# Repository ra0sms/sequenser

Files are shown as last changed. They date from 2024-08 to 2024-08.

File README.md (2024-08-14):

# Sequencer

More information - https://ra0sms.com/sequencer-2/

It works in two modes:

1. PA BIAS mode (`MODE` jumper is opened)

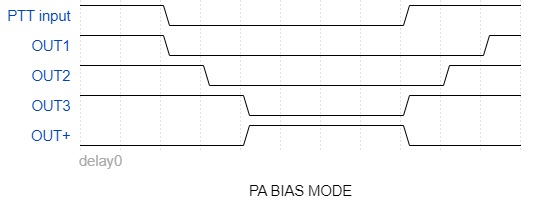
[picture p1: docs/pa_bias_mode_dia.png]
pa_bias_mode_dia
   

2. LNA mode (`MODE` jumper is closed)

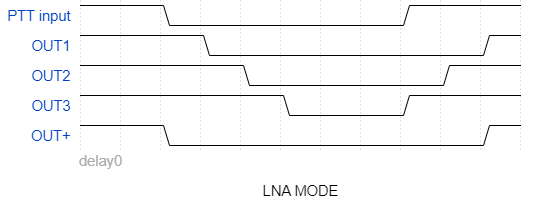
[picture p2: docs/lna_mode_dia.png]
lna_mode_dia
   

--------------------------------------------------------------
PCB dimension: 70*45mm

Consumption current: 30mA

Switch current: up to 1A

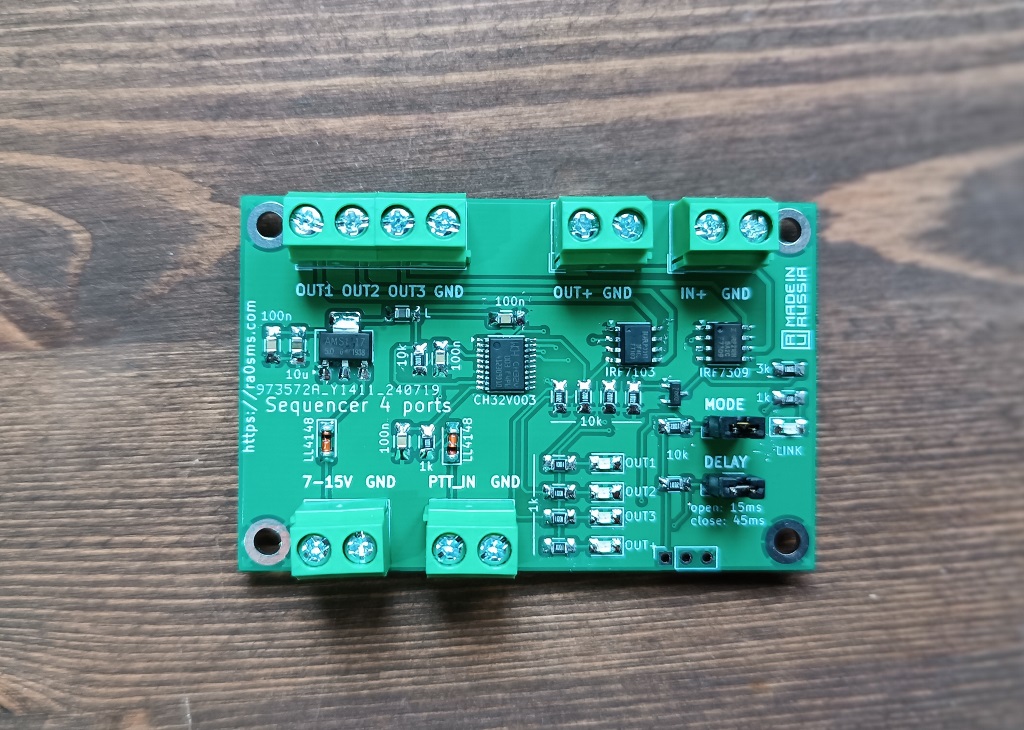
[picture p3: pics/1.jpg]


### Schematic

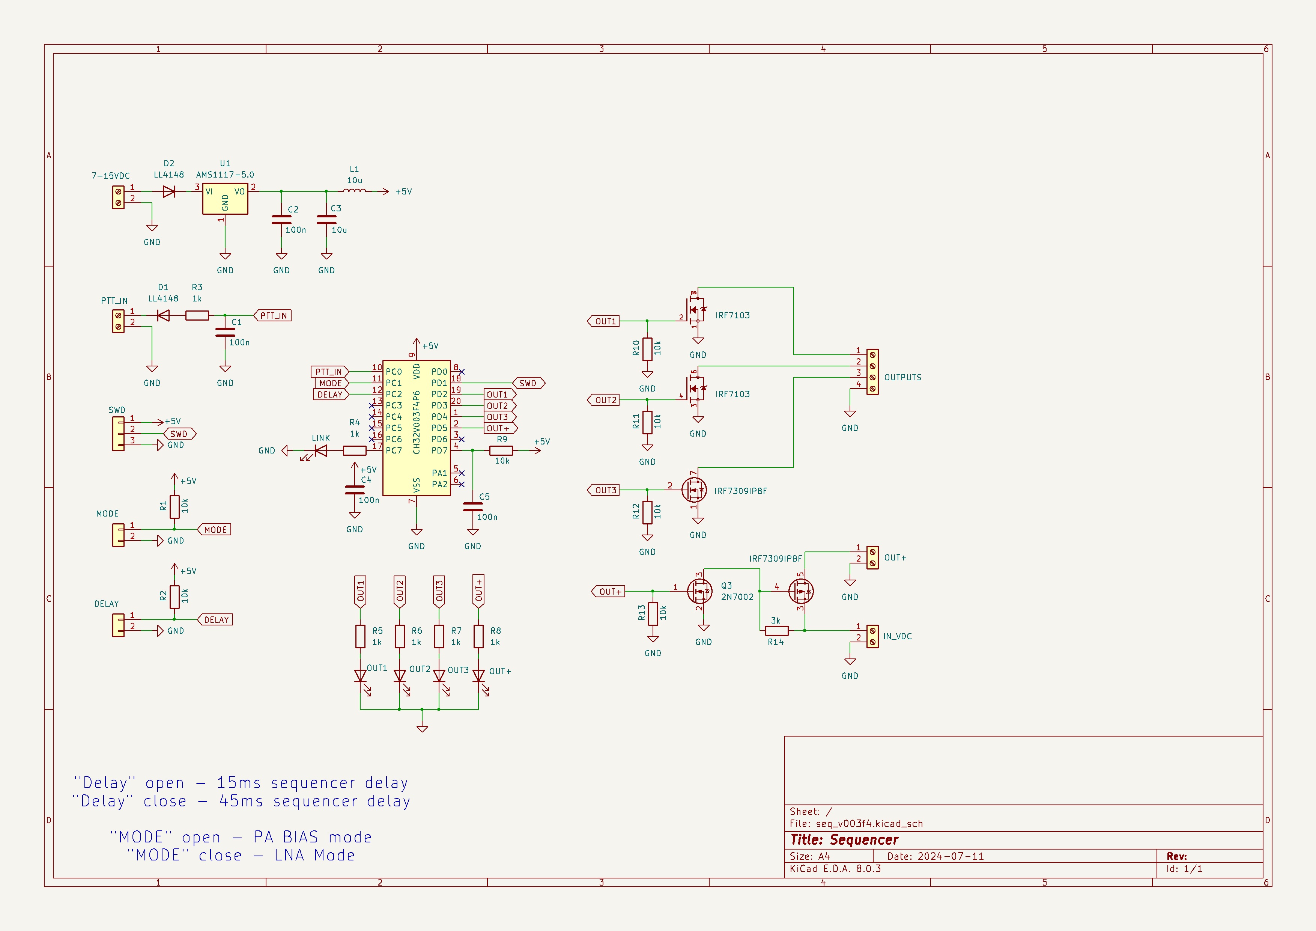
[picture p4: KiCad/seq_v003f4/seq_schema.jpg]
seq_schema


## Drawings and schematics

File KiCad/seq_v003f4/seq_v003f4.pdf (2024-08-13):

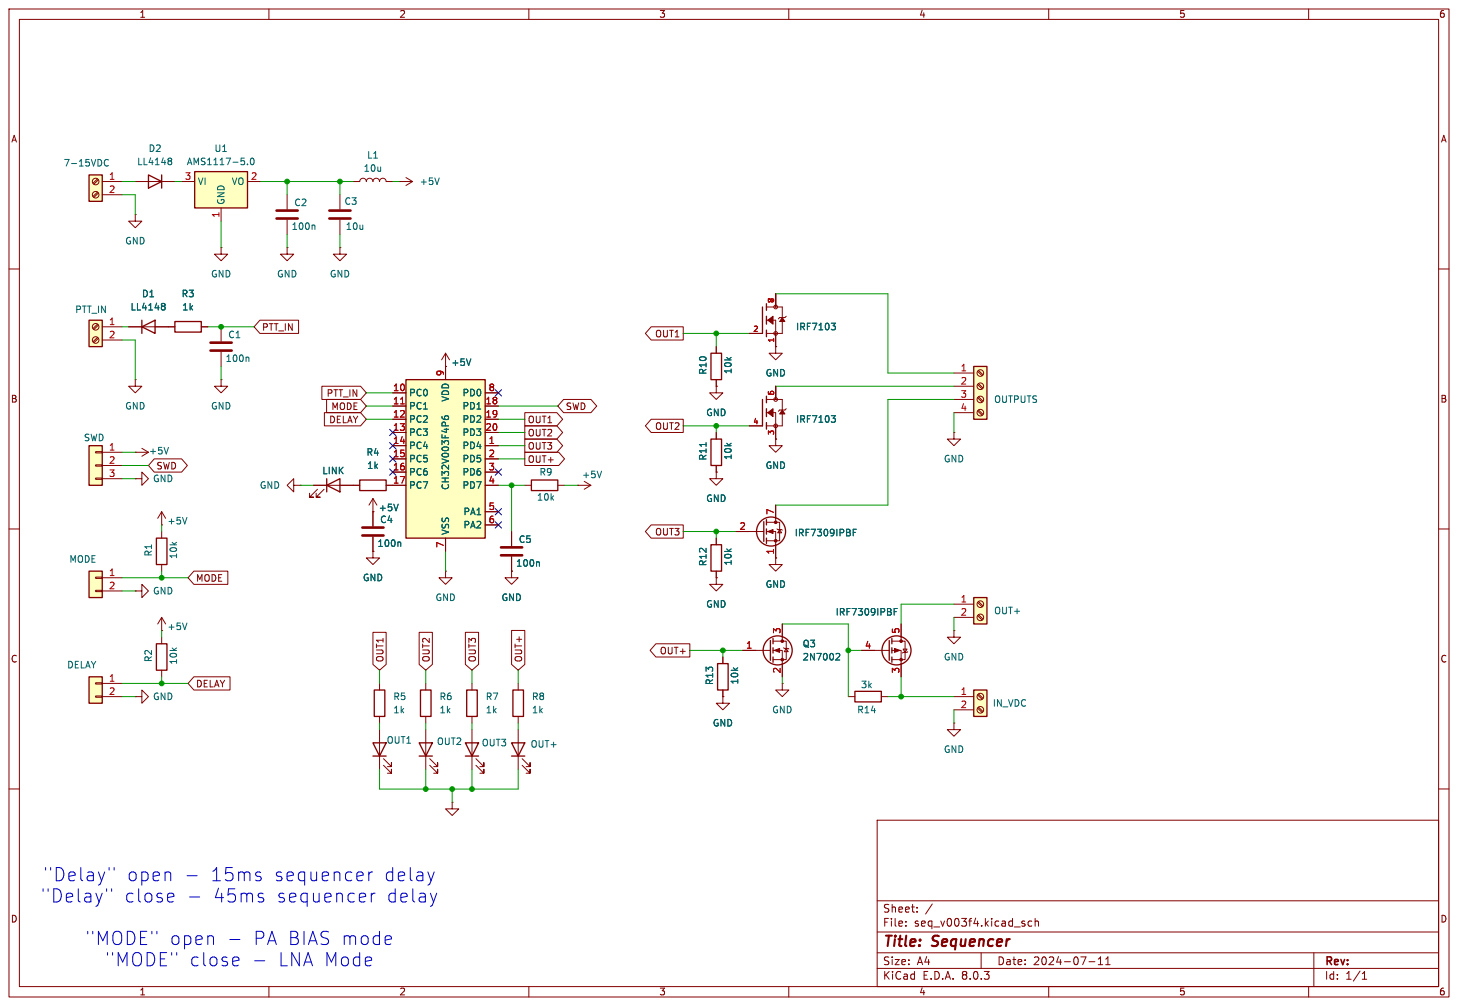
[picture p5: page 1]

Id: 1/1 Title: Sequencer File: seq_v003f4.kicad_sch Sheet: / R6

"Delay" open - 15ms sequencer delay
"Delay" close - 45ms sequencer delay

"MODE" open - PA BIAS mode
"MODE" close - LNA Mode

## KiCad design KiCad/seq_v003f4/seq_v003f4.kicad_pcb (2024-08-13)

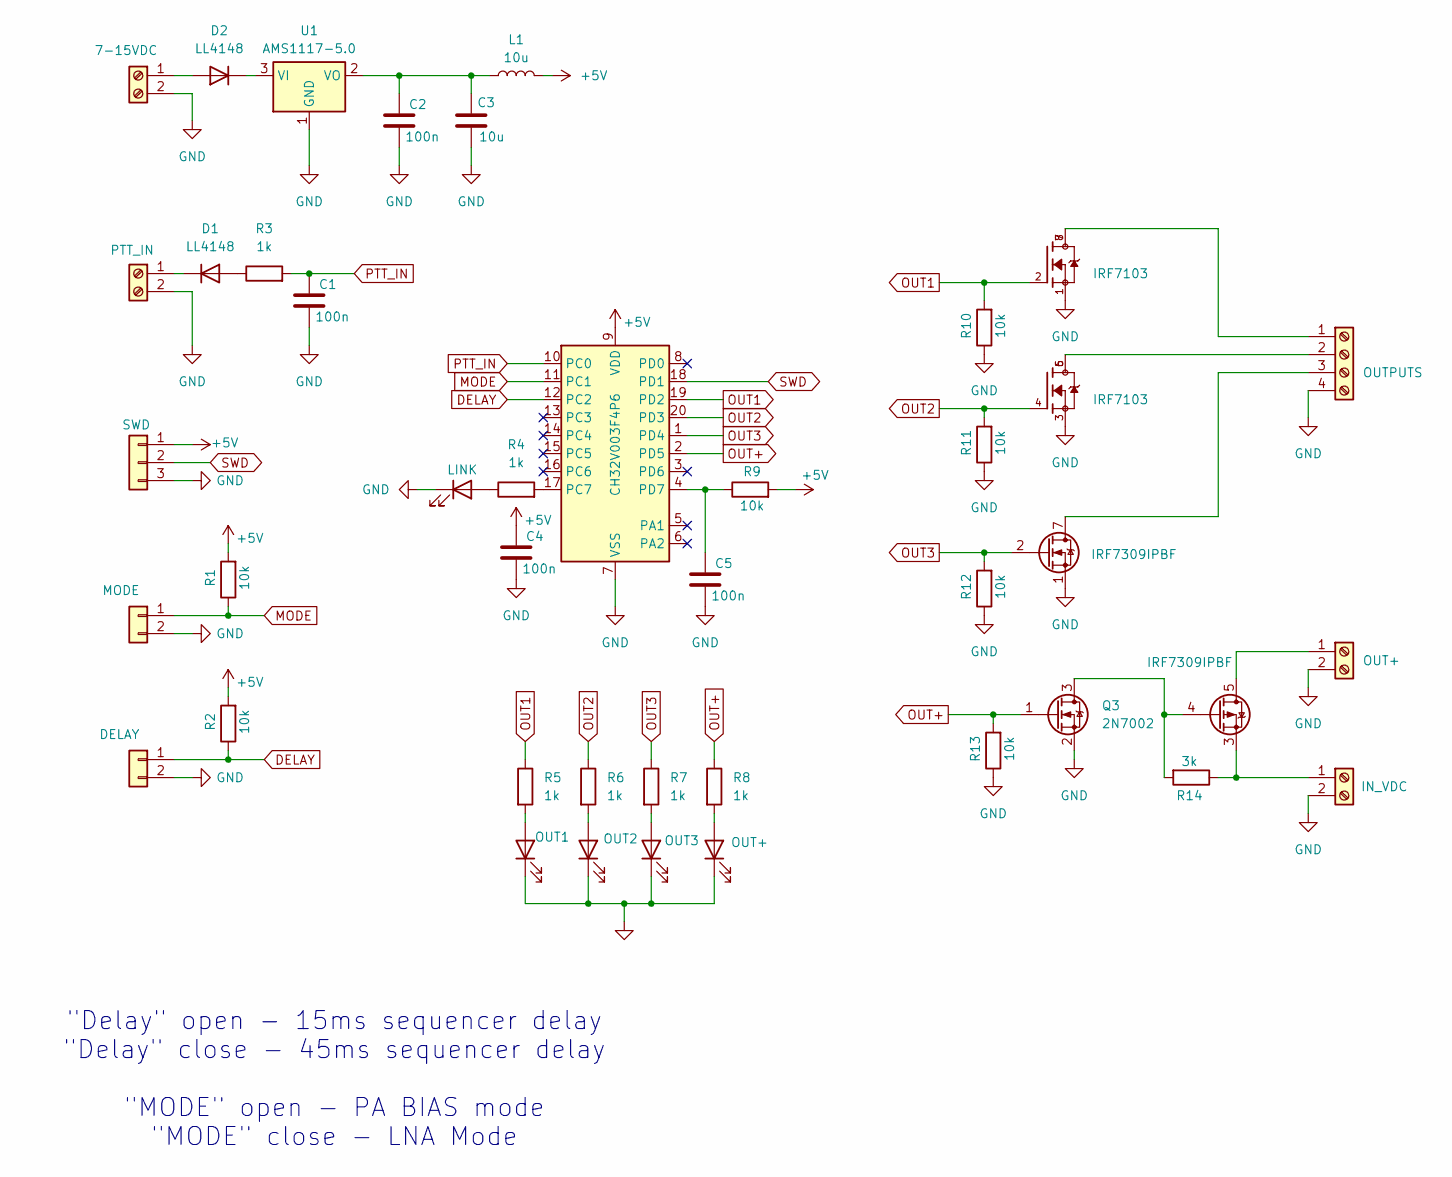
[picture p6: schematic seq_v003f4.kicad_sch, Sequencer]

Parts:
C1, C2, C4, C5: 100n; C_1206_3216Metric_Pad1.33x1.80mm_HandSolder
C3: 10u; C_1206_3216Metric_Pad1.33x1.80mm_HandSolder
D1, D2: LL4148; D_MiniMELF
D3: LINK; LED_1206_3216Metric
D4: OUT1; LED_1206_3216Metric
D5: OUT2; LED_1206_3216Metric
D6: OUT3; LED_1206_3216Metric
D7: OUT+; LED_1206_3216Metric
J1: 7-15VDC; TerminalBlock_MetzConnect_Type055_RT01502HDWU_1x02_P5.00mm_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
J2: PTT_IN; TerminalBlock_MetzConnect_Type055_RT01502HDWU_1x02_P5.00mm_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
J3: SWD; PinSocket_1x03_P2.54mm_Vertical
J4: MODE; PinHeader_1x02_P2.54mm_Vertical
J5: DELAY; PinHeader_1x02_P2.54mm_Vertical
J6: OUTPUTS; TerminalBlock_MetzConnect_Type055_RT01504HDWU_1x04_P5.00mm_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
J7: OUT+; TerminalBlock_MetzConnect_Type055_RT01502HDWU_1x02_P5.00mm_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
J8: IN_VDC; TerminalBlock_MetzConnect_Type055_RT01502HDWU_1x02_P5.00mm_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
L1: 10u; L_1206_3216Metric
Q1: IRF7103; SOIC-8_3.9x4.9mm_P1.27mm; PARTREV 02/09/10
Q2: IRF7309IPBF; SOIC-8_3.9x4.9mm_P1.27mm
Q3: 2N7002; SOT-23
R1, R2, R9, R10, R11, R12, R13: 10k; R_1206_3216Metric
R3, R4, R5, R6, R7, R8: 1k; R_1206_3216Metric
R14: 3k; R_1206_3216Metric
U1: AMS1117-5.0; SOT-223-3_TabPin2
U2: CH32V003F4P6; TSSOP-20_4.4x6.5mm_P0.65mm

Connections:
+5V: C4.1, J3.1, L1.2, R1.2, R2.2, R9.2, U2.9 (VDD)
DELAY: J5.1, R2.1, U2.12 (PC2)
GND: C1.2, C2.2, C3.2, C4.2, C5.2, D3.1 (K), D4.1 (K), D5.1 (K), D6.1 (K), D7.1 (K), J1.2, J2.2, J3.3, J4.2, J5.2, J6.4, J7.2, J8.2, Q1.1, Q1.3, Q2.1 (S), Q3.2 (S), R10.1, R11.1, R12.1, R13.1, U1.1 (GND), U2.7 (VSS)
MODE: J4.1, R1.1, U2.11 (PC1)
unnamed: D1.2 (A), R3.1
unnamed: D1.1 (K), J2.1
unnamed: D2.2 (A), J1.1
unnamed: D2.1 (K), U1.3 (VI)
unnamed: D3.2 (A), R4.1
unnamed: D4.2 (A), R5.2
unnamed: D5.2 (A), R6.2
unnamed: D6.2 (A), R7.2
unnamed: D7.2 (A), R8.2
unnamed: J6.1, Q1.7, Q1.8
unnamed: J6.2, Q1.5, Q1.6
unnamed: J6.3, Q2.7 (D), Q2.8 (D)
unnamed: J7.1, Q2.5 (D), Q2.6 (D)
unnamed: J8.1, Q2.3 (1), R14.1
unnamed: Q2.4 (G), Q3.3 (D), R14.2
unnamed: C2.1, C3.1, L1.1, U1.2 (VO)
unnamed: R4.2, U2.17 (PC7)
unnamed: C5.1, R9.1, U2.4 (PD7)
OUT1: Q1.2, R5.1, R10.2, U2.19 (PD2)
OUT2: Q1.4, R6.1, R11.2, U2.20 (PD3)
OUT3: Q2.2 (G), R7.1, R12.2, U2.1 (PD4)
OUT+: Q3.1 (G), R8.1, R13.2, U2.2 (PD5)
PTT_IN: C1.1, R3.2, U2.10 (PC0)
SWD: J3.2, U2.18 (PD1)

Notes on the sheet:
"Delay" open - 15ms sequencer delay "Delay" close - 45ms sequencer delay "MODE" open - PA BIAS mode "MODE" close - LNA Mode

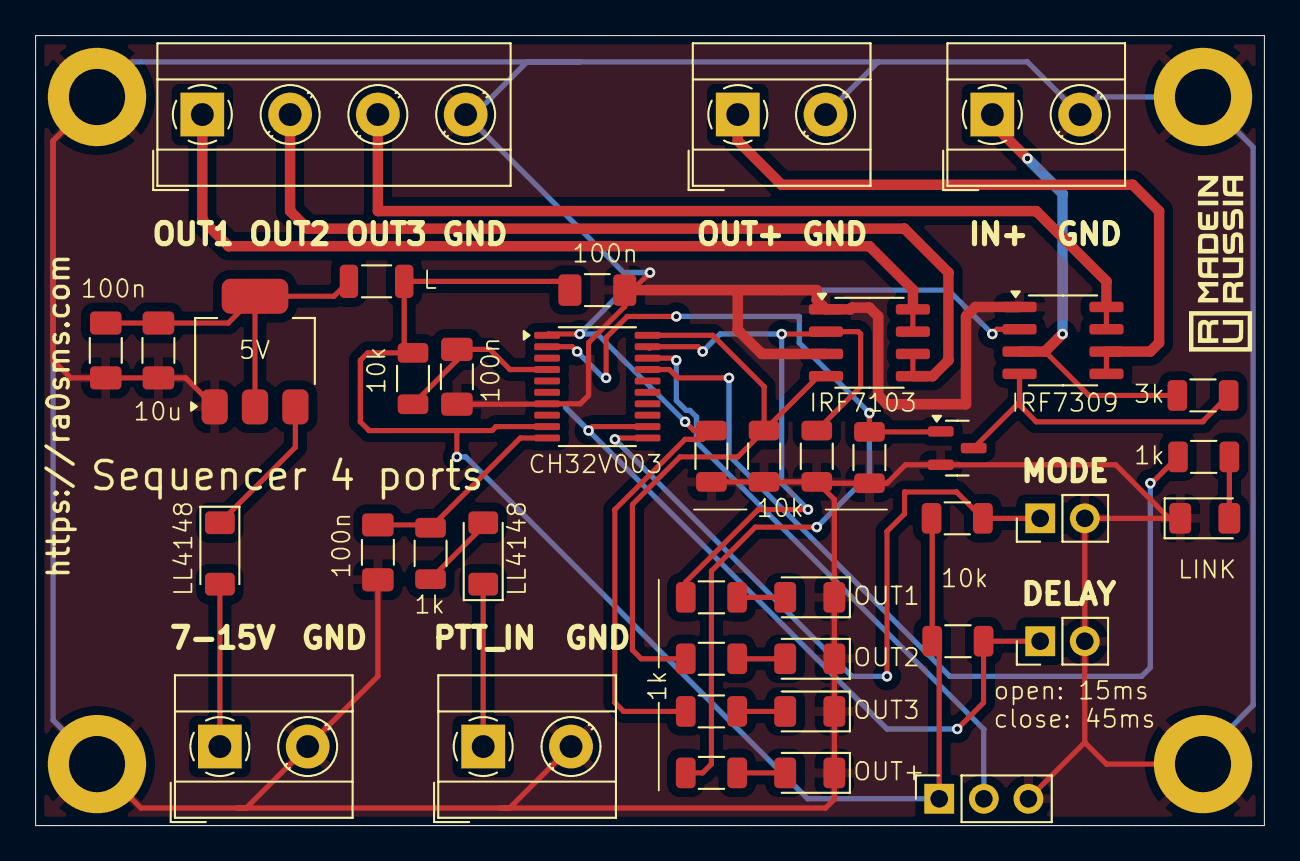
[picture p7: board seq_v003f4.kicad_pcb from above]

Board: 2 copper layers, 70.0 x 45.0 mm, 40 parts (0 on the bottom side), 28 nets.

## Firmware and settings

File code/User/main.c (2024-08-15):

#include "debug.h"

#define LED_Pin GPIO_Pin_7
#define LED_GPIO_Port GPIOC
//**************
#define OUT_1 GPIO_Pin_2
#define OUT_1_Port GPIOD
//***************
#define OUT_2 GPIO_Pin_3
#define OUT_2_Port GPIOD
//***************
#define OUT_3 GPIO_Pin_4
#define OUT_3_Port GPIOD
//***************
#define OUT_PLUS GPIO_Pin_5
#define OUT_PLUS_Port GPIOD
//***************
#define MODE GPIO_Pin_1
#define MODE_Port GPIOC
//***************
#define PTT_IN GPIO_Pin_0
#define PTT_IN_Port GPIOC
//***************
#define DELAY GPIO_Pin_2
#define DELAY_Port GPIOC
//***************
#define MAX_DELAY 45
#define MIN_DELAY 15


vu8 delay_ms = 0;

void Timer2_INIT(u16 arr, u16 psc)
{
    TIM_TimeBaseInitTypeDef TIMBase_InitStruct;
    NVIC_InitTypeDef NVIC_InitStruct;

    RCC_APB1PeriphClockCmd(RCC_APB1Periph_TIM2, ENABLE);

    TIMBase_InitStruct.TIM_Period = arr;
    TIMBase_InitStruct.TIM_CounterMode = TIM_CounterMode_Up;
    TIMBase_InitStruct.TIM_Prescaler = psc;
    TIMBase_InitStruct.TIM_ClockDivision = TIM_CKD_DIV1;
    TIM_TimeBaseInit(TIM2, &TIMBase_InitStruct);

    TIM_ITConfig(TIM2, TIM_IT_Update, ENABLE);

    NVIC_InitStruct.NVIC_IRQChannel = TIM2_IRQn;
    NVIC_InitStruct.NVIC_IRQChannelPreemptionPriority = 5;
    NVIC_InitStruct.NVIC_IRQChannelSubPriority = 5;
    NVIC_InitStruct.NVIC_IRQChannelCmd = ENABLE;
    NVIC_Init(&NVIC_InitStruct);
    TIM_Cmd(TIM2, ENABLE);
}

void GPIO_INIT(void)
{
    GPIO_InitTypeDef GPIO_InitStructure = {0};
    RCC_APB2PeriphClockCmd(RCC_APB2Periph_GPIOC, ENABLE);
    RCC_APB2PeriphClockCmd(RCC_APB2Periph_GPIOD, ENABLE);

    GPIO_InitStructure.GPIO_Pin = LED_Pin;
    GPIO_InitStructure.GPIO_Mode = GPIO_Mode_Out_PP;
    GPIO_InitStructure.GPIO_Speed = GPIO_Speed_50MHz;
    GPIO_Init(LED_GPIO_Port, &GPIO_InitStructure);

    GPIO_InitStructure.GPIO_Pin = OUT_1;
    GPIO_InitStructure.GPIO_Mode = GPIO_Mode_Out_PP;
    GPIO_InitStructure.GPIO_Speed = GPIO_Speed_50MHz;
    GPIO_Init(OUT_1_Port, &GPIO_InitStructure);

    GPIO_InitStructure.GPIO_Pin = OUT_2;
    GPIO_InitStructure.GPIO_Mode = GPIO_Mode_Out_PP;
    GPIO_InitStructure.GPIO_Speed = GPIO_Speed_50MHz;
    GPIO_Init(OUT_2_Port, &GPIO_InitStructure);

    GPIO_InitStructure.GPIO_Pin = OUT_3;
    GPIO_InitStructure.GPIO_Mode = GPIO_Mode_Out_PP;
    GPIO_InitStructure.GPIO_Speed = GPIO_Speed_50MHz;
    GPIO_Init(OUT_3_Port, &GPIO_InitStructure);

    GPIO_InitStructure.GPIO_Pin = OUT_PLUS;
    GPIO_InitStructure.GPIO_Mode = GPIO_Mode_Out_PP;
    GPIO_InitStructure.GPIO_Speed = GPIO_Speed_50MHz;
    GPIO_Init(OUT_PLUS_Port, &GPIO_InitStructure);

    GPIO_InitStructure.GPIO_Pin = PTT_IN;
    GPIO_InitStructure.GPIO_Mode = GPIO_Mode_IPU;
    GPIO_InitStructure.GPIO_Speed = GPIO_Speed_50MHz;
    GPIO_Init(PTT_IN_Port, &GPIO_InitStructure);
    GPIO_WriteBit(PTT_IN_Port, PTT_IN, Bit_SET);

    GPIO_InitStructure.GPIO_Pin = MODE;
    GPIO_InitStructure.GPIO_Mode = GPIO_Mode_IPU;
    GPIO_InitStructure.GPIO_Speed = GPIO_Speed_50MHz;
    GPIO_Init(MODE_Port, &GPIO_InitStructure);

    GPIO_InitStructure.GPIO_Pin = DELAY;
    GPIO_InitStructure.GPIO_Mode = GPIO_Mode_IPU;
    GPIO_InitStructure.GPIO_Speed = GPIO_Speed_50MHz;
    GPIO_Init(DELAY_Port, &GPIO_InitStructure);

    Delay_Ms(200);

    GPIO_WriteBit(OUT_1_Port, OUT_1, Bit_RESET);
    GPIO_WriteBit(OUT_2_Port, OUT_2, Bit_RESET);
    GPIO_WriteBit(OUT_3_Port, OUT_3, Bit_RESET);
    GPIO_WriteBit(OUT_PLUS_Port, OUT_PLUS, Bit_RESET);

}

void bias_mode(){
    vu8 flag_on = 0;
    while (!GPIO_ReadInputDataBit(PTT_IN_Port, PTT_IN)){
        flag_on = 1;
        GPIO_WriteBit(OUT_1_Port, OUT_1, Bit_SET);
        Delay_Ms(delay_ms);
        GPIO_WriteBit(OUT_2_Port, OUT_2, Bit_SET);
        Delay_Ms(delay_ms);
        GPIO_WriteBit(OUT_3_Port, OUT_3, Bit_SET);
        GPIO_WriteBit(OUT_PLUS_Port, OUT_PLUS, Bit_SET);
    }
    if (flag_on){
        flag_on = 0;
        GPIO_WriteBit(OUT_PLUS_Port, OUT_PLUS, Bit_RESET);
        GPIO_WriteBit(OUT_3_Port, OUT_3, Bit_RESET);
        Delay_Ms(delay_ms);
        GPIO_WriteBit(OUT_2_Port, OUT_2, Bit_RESET);
        Delay_Ms(delay_ms);
        GPIO_WriteBit(OUT_1_Port, OUT_1, Bit_RESET);
    }
}

void LNA_mode(){
    vu8 flag_on = 0;
    while (!GPIO_ReadInputDataBit(PTT_IN_Port, PTT_IN)){
        flag_on = 1;
        GPIO_WriteBit(OUT_PLUS_Port, OUT_PLUS, Bit_RESET);
        Delay_Ms(delay_ms);
        GPIO_WriteBit(OUT_1_Port, OUT_1, Bit_SET);
        Delay_Ms(delay_ms);
        GPIO_WriteBit(OUT_2_Port, OUT_2, Bit_SET);
        Delay_Ms(delay_ms);
        GPIO_WriteBit(OUT_3_Port, OUT_3, Bit_SET);
    }
    if (flag_on){
        flag_on = 0;
        GPIO_WriteBit(OUT_3_Port, OUT_3, Bit_RESET);
        Delay_Ms(delay_ms);
        GPIO_WriteBit(OUT_2_Port, OUT_2, Bit_RESET);
        Delay_Ms(delay_ms);
        GPIO_WriteBit(OUT_1_Port, OUT_1, Bit_RESET);
        Delay_Ms(delay_ms);
        GPIO_WriteBit(OUT_PLUS_Port, OUT_PLUS, Bit_SET);
    }
}

int main(void)
{
    NVIC_PriorityGroupConfig(NVIC_PriorityGroup_1);
    SystemCoreClockUpdate();
    Delay_Init();
    GPIO_INIT();
    Timer2_INIT(999, 23999);
    while(1)
    {
        if (GPIO_ReadInputDataBit(DELAY_Port, DELAY)) delay_ms = MIN_DELAY;
        else delay_ms = MAX_DELAY;
        if (GPIO_ReadInputDataBit(MODE_Port, MODE)) {
            GPIO_WriteBit(OUT_PLUS_Port, OUT_PLUS, Bit_RESET);
            bias_mode();
        }
        else {
            GPIO_WriteBit(OUT_PLUS_Port, OUT_PLUS, Bit_SET);
            LNA_mode();
        }

    }
}

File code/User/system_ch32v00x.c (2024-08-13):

/********************************** (C) COPYRIGHT *******************************
 * File Name          : system_ch32v00x.c
 * Author             : WCH
 * Version            : V1.0.0
 * Date               : 2023/12/26
 * Description        : CH32V00x Device Peripheral Access Layer System Source File.
*********************************************************************************
* Copyright (c) 2021 Nanjing Qinheng Microelectronics Co., Ltd.
* Attention: This software (modified or not) and binary are used for 
* microcontroller manufactured by Nanjing Qinheng Microelectronics.
*******************************************************************************/
#include <ch32v00x.h>

/* 
* Uncomment the line corresponding to the desired System clock (SYSCLK) frequency (after 
* reset the HSI is used as SYSCLK source).
* If none of the define below is enabled, the HSI is used as System clock source. 
*/

//#define SYSCLK_FREQ_8MHz_HSI    8000000
//#define SYSCLK_FREQ_24MHZ_HSI   HSI_VALUE
#define SYSCLK_FREQ_48MHZ_HSI   48000000
//#define SYSCLK_FREQ_8MHz_HSE    8000000
//#define SYSCLK_FREQ_24MHz_HSE   HSE_VALUE
//#define SYSCLK_FREQ_48MHz_HSE   48000000

/* Clock Definitions */
#ifdef SYSCLK_FREQ_8MHz_HSI
  uint32_t SystemCoreClock         = SYSCLK_FREQ_8MHz_HSI;          /* System Clock Frequency (Core Clock) */
#elif defined SYSCLK_FREQ_24MHZ_HSI
  uint32_t SystemCoreClock         = SYSCLK_FREQ_24MHZ_HSI;        /* System Clock Frequency (Core Clock) */
#elif defined SYSCLK_FREQ_48MHZ_HSI
  uint32_t SystemCoreClock         = SYSCLK_FREQ_48MHZ_HSI;        /* System Clock Frequency (Core Clock) */
#elif defined SYSCLK_FREQ_8MHz_HSE
  uint32_t SystemCoreClock         = SYSCLK_FREQ_8MHz_HSE;         /* System Clock Frequency (Core Clock) */
#elif defined SYSCLK_FREQ_24MHz_HSE
  uint32_t SystemCoreClock         = SYSCLK_FREQ_24MHz_HSE;        /* System Clock Frequency (Core Clock) */
#elif defined SYSCLK_FREQ_48MHz_HSE
  uint32_t SystemCoreClock         = SYSCLK_FREQ_48MHz_HSE;        /* System Clock Frequency (Core Clock) */
#else
  uint32_t SystemCoreClock         = HSI_VALUE;
#endif

__I uint8_t AHBPrescTable[16] = {1, 2, 3, 4, 5, 6, 7, 8, 1, 2, 3, 4, 5, 6, 7, 8};


/* system_private_function_proto_types */
static void SetSysClock(void);

#ifdef SYSCLK_FREQ_8MHz_HSI
  static void SetSysClockTo_8MHz_HSI(void);
#elif defined SYSCLK_FREQ_24MHZ_HSI
  static void SetSysClockTo_24MHZ_HSI(void);
#elif defined SYSCLK_FREQ_48MHZ_HSI
  static void SetSysClockTo_48MHZ_HSI(void);
#elif defined SYSCLK_FREQ_8MHz_HSE
  static void SetSysClockTo_8MHz_HSE(void);
#elif defined SYSCLK_FREQ_24MHz_HSE
  static void SetSysClockTo_24MHz_HSE(void);
#elif defined SYSCLK_FREQ_48MHz_HSE
  static void SetSysClockTo_48MHz_HSE(void);
#endif


/*********************************************************************
 * @fn      SystemInit
 *
 * @brief   Setup the microcontroller system Initialize the Embedded Flash Interface,
 *        the PLL and update the SystemCoreClock variable.
 *
 * @return  none
 */
void SystemInit (void)
{
  RCC->CTLR |= (uint32_t)0x00000001;
  RCC->CFGR0 &= (uint32_t)0xF8FF0000;
  RCC->CTLR &= (uint32_t)0xFEF6FFFF;
  RCC->CTLR &= (uint32_t)0xFFFBFFFF;
  RCC->CFGR0 &= (uint32_t)0xFFFEFFFF;
  RCC->INTR = 0x009F0000;

  RCC_AdjustHSICalibrationValue(0x10);

  SetSysClock();
}


/*********************************************************************
 * @fn      SystemCoreClockUpdate
 *
 * @brief   Update SystemCoreClock variable according to Clock Register Values.
 *
 * @return  none
 */
void SystemCoreClockUpdate (void)
{
    uint32_t tmp = 0, pllsource = 0;

    tmp = RCC->CFGR0 & RCC_SWS;

    switch (tmp)
    {
        case 0x00:
            SystemCoreClock = HSI_VALUE;
            break;
        case 0x04:
            SystemCoreClock = HSE_VALUE;
            break;
        case 0x08:
            pllsource = RCC->CFGR0 & RCC_PLLSRC;
            if (pllsource == 0x00)
            {
                SystemCoreClock = HSI_VALUE * 2;
            }
            else
            {
                SystemCoreClock = HSE_VALUE * 2;
            }
            break;
        default:
            SystemCoreClock = HSI_VALUE;
            break;
    }

    tmp = AHBPrescTable[((RCC->CFGR0 & RCC_HPRE) >> 4)];

    if(((RCC->CFGR0 & RCC_HPRE) >> 4) < 8)
    {
        SystemCoreClock /= tmp;
    }
    else
    {
        SystemCoreClock >>= tmp;
    }
}


/*********************************************************************
 * @fn      SetSysClock
 *
 * @brief   Configures the System clock frequency, HCLK, PCLK2 and PCLK1 prescalers.
 *
 * @return  none
 */
static void SetSysClock(void)
{
RCC->APB2PCENR |= RCC_APB2Periph_GPIOD;
GPIOD->CFGLR&=(~0xF0);
GPIOD->CFGLR|=0x80;
GPIOD->BSHR =0x2;
//GPIO_IPD_Unused();
#ifdef SYSCLK_FREQ_8MHz_HSI
    SetSysClockTo_8MHz_HSI();
#elif defined SYSCLK_FREQ_24MHZ_HSI
    SetSysClockTo_24MHZ_HSI();
#elif defined SYSCLK_FREQ_48MHZ_HSI
    SetSysClockTo_48MHZ_HSI();
#elif defined SYSCLK_FREQ_8MHz_HSE
    SetSysClockTo_8MHz_HSE();
#elif defined SYSCLK_FREQ_24MHz_HSE
    SetSysClockTo_24MHz_HSE();
#elif defined SYSCLK_FREQ_48MHz_HSE
    SetSysClockTo_48MHz_HSE();
#endif
 
 /* If none of the define above is enabled, the HSI is used as System clock.
  * source (default after reset) 
	*/ 
}


#ifdef SYSCLK_FREQ_8MHz_HSI

/*********************************************************************
 * @fn      SetSysClockTo_8MHz_HSI
 *
 * @brief   Sets HSI as System clock source and configure HCLK, PCLK2 and PCLK1 prescalers.
 *
 * @return  none
 */
static void SetSysClockTo_8MHz_HSI(void)
{
    /* Flash 0 wait state */
    FLASH->ACTLR &= (uint32_t)((uint32_t)~FLASH_ACTLR_LATENCY);
    FLASH->ACTLR |= (uint32_t)FLASH_ACTLR_LATENCY_0;

    /* HCLK = SYSCLK = APB1 */
    RCC->CFGR0 |= (uint32_t)RCC_HPRE_DIV3;
}

#elif defined SYSCLK_FREQ_24MHZ_HSI

/*********************************************************************
 * @fn      SetSysClockTo_24MHZ_HSI
 *
 * @brief   Sets System clock frequency to 24MHz and configure HCLK, PCLK2 and PCLK1 prescalers.
 *
 * @return  none
 */
static void SetSysClockTo_24MHZ_HSI(void)
{
    /* Flash 0 wait state */
    FLASH->ACTLR &= (uint32_t)((uint32_t)~FLASH_ACTLR_LATENCY);
    FLASH->ACTLR |= (uint32_t)FLASH_ACTLR_LATENCY_0;

    /* HCLK = SYSCLK = APB1 */
    RCC->CFGR0 |= (uint32_t)RCC_HPRE_DIV1;
}


#elif defined SYSCLK_FREQ_48MHZ_HSI
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
